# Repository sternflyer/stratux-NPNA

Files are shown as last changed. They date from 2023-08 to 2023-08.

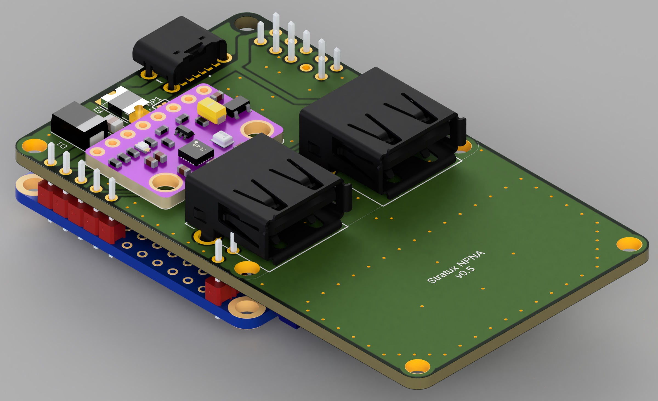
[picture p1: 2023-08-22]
PCB/PCB_BOTTOM_ISO.jpg

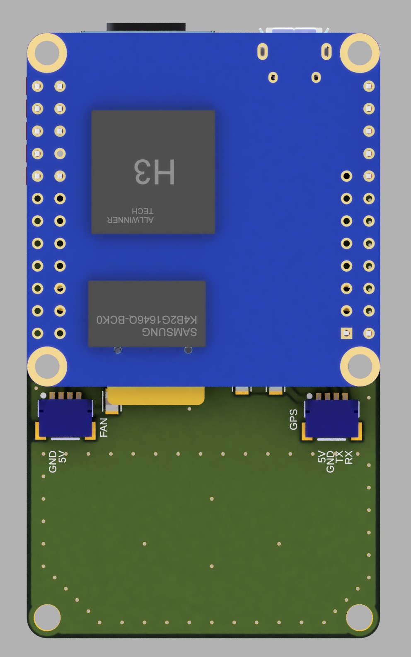
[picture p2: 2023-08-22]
PCB/PCB_TOP.jpg

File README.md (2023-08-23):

# stratux-NPNA
Stratux Europe running on a NanoPi Neo Air. Probably the smallest Stratux System possible. The case including fan and GPS ist juts 79x48x33mm in size.
Based on the wonderful work of https://github.com/b3nn0/stratux and https://github.com/VirusPilot/stratux-pi4.

```diff
-!!WARNING!!- This is work in progress. It might not work! It might fail after a while! DO NOT RELY ON IT DURING FLIGHT!!
```

# Installation
- Install a fresh version or Armbian Bullseye (I used 23.02.0 with 5.15.91 kernel) on your NanoPi Neo Air. Since there is no official Armbian support for the NanoPi Neo Air, you need to compile it yourself. For compatibility reason, you need to add ```BOOTFS_TYPE="fat"``` to the NanoPi Neo Air config file before compiling Armbian.
For best performance, install Armbian to the internal eMMC of the NanoPi Neo Air.
- Boot up Armbian Bullseye and connect to your WiFi. The initial Armbian setup script will guide you through that process.
- Download and run the Stratux NPNA setup script:
```
wget https://raw.githubusercontent.com/sternflyer/stratux-NPNA/main/stratux-NPNA-setup.sh
chmod +x stratux-NPNA-setup.sh
sudo ./stratux-NPNA-setup.sh
```

- Reboot when promted 

# Hardware
Description of the hardware used. You can find a shopping list at the end.

## NanoPi Neo Air
The NanoPi Neo Air is a very minimalistic SBC. Measuring only 40x40mm, it is probably one of the smallest SBC around. With no external connectors aside a mini USB port and a SD-Card slot. 
However, two USB-Ports, UART and I2C are available via pinheader. For detailed description see https://wiki.friendlyelec.com/wiki/index.php/NanoPi_NEO_Air.

## SDR
I'm using two Nooelec NESDR Nano 2 to receive ADS-B (1090 MHz) and OGN (868 MHz). Without plastic housing the SDRs fit under the custom PCB. The Fan provides proficient cooling. With a MCX to SMA adaptor you can remove the antennas for transport.

## GPS
I was having some difficulties to find a GPS that is working. The SDRs have quite some interference into the GPS frequency range and compromise reception. After many trial and error I found that the Beitian BE-252i module works best. It has a u-blox UBX-M10050 chip with a 25*25mm ceramic antenna.

## AHRS
I'm sing the popular GY-91 board with BMP280 and a MPU9250 accelerometer, gyroscope and compass. Due to EOL of MPU9250 cips, there are many boards with a MPU6050. The MPU6050 is the same as the MPU9250, but without a compass. Since compass is not used in Stratux, MPU6050 should work just as well (not tested).

## PCB
For connecting the peripherlas (two SDRs, a GPS, fan, and GY-91 AHRS board) I designed a PCB to connect to the pinheader. The smallest SMD components are 0805, still solderable by hand. Make sure to cut the pins of the USB-plugs as short as possible (after soldering) to prevent them from touching the NanoPi Air. Use the PCB spacers for correct distance between NanoPi Air and PCB.

## Case
The case can be 3D-printed. With the fan it provides sifficient cooling for the NanoPi Air and the SDRs. With the suction cup you can fix it to a window. Make sure to print it with white ABS oder PETG filament since it might get hot in direct sunlight. PLA will get soft if you leave it in the sun behind the window (aks me how i know...).

# Shopping list
These are the components you need: TBA
- NanoPi Neo Air (https://amzn.to/3KQvrtV)
- SDRs (https://amzn.to/3qOO4Ye)
- GPS Module (https://s.click.aliexpress.com/e/_Ddqhyxp)
- 30x30x7mm Fan (https://amzn.to/45lR8dI)
- GY-91 (https://amzn.to/3sjisum)
- PCB (need to get your own, GERBER files provided in [[PCB/](https://github.com/sternflyer/stratux-NPNA/PCB/stratux-NPNA-PCB_v05.zip))
- PCB components ([PCB/Partlist PCB.csv](https://github.com/sternflyer/stratux-NPNA/blob/main/PCB/Partlist%20PCB.csv))
- PETG or ABS for the case (https://amzn.to/3P5NSgH)
- Suction cup (https://amzn.to/3E7OOLq)

# NanoPi Neo Air vs. Raspberry Pi 3B+
Here is a small comparison of the NanoPi Neo Air and the Raspberry Pi 3B+ when running Stratux. Comparison was done with two Nooelec NESDR Nano 2, a GPS (USB BL1 GPS Module at rPi 3B+, Beitian BE-252i GPS on UART at NeoPi Nano Air) and a GY-91 Module as AHRS connected. TBA

| | raspberry Pi 3B+ | NanoPi Neo Air |
|-----|---|---|
Power Consumption | 1154 mA | 985 mA |
Avg. CPU load | 61 % | 64 % |
Avg. CPU Temp. | 42 °C | 45 °C |

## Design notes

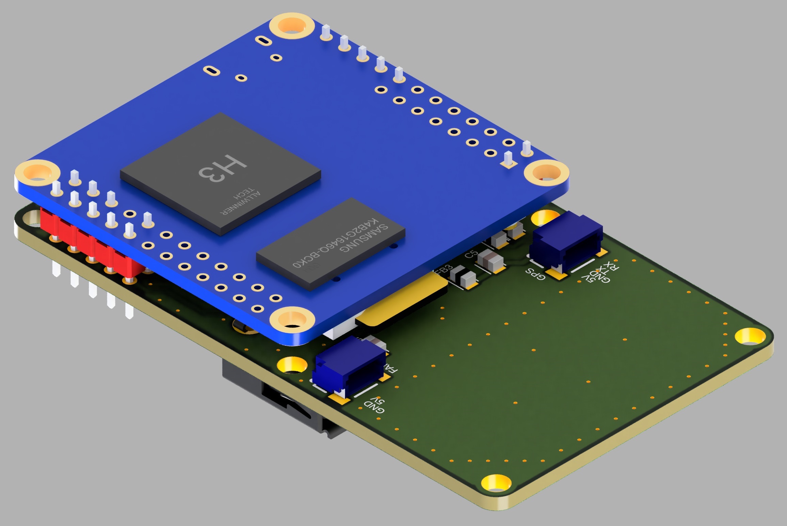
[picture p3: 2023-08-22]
PCB/PCB_TOP_ISO.jpg

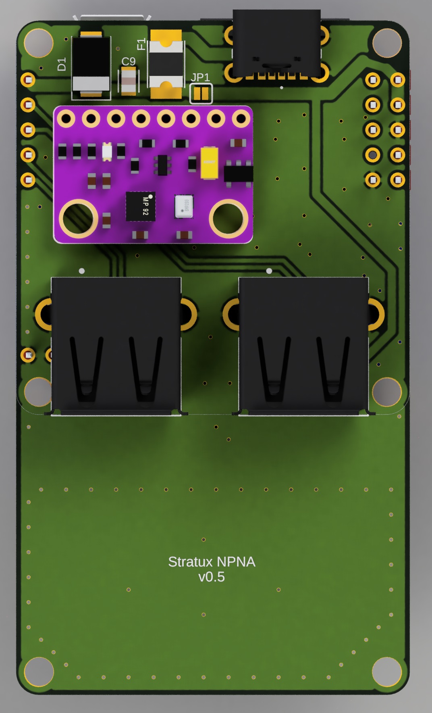
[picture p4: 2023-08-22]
PCB/PCB_BOTTOM.jpg

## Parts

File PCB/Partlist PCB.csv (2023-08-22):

Part | Value | Device | Package | Description | Source
C1 | 22uF | C_CHIP-0805 | 0805 | Capacitor | https://www.reichelt.de/smd-vielschicht-0805-22-f-x5r-10-6-3v-85-c-kem-x5r0805-22u-p207090.html
C2 | 100nF | C_CHIP-0805 | 0805 | Capacitor | https://www.reichelt.de/vielschicht-kerko-100nf-50v-125-c-kem-x7r0805-100n-p207073.html
C3 | 22uF | C_CHIP-0805 | 0805 | Capacitor | https://www.reichelt.de/smd-vielschicht-0805-22-f-x5r-10-6-3v-85-c-kem-x5r0805-22u-p207090.html
C4 | 100nF | C_CHIP-0805 | 0805 | Capacitor | https://www.reichelt.de/vielschicht-kerko-100nf-50v-125-c-kem-x7r0805-100n-p207073.html
C5 | 100nF | C_CHIP-0805 | 0805 | Capacitor | https://www.reichelt.de/vielschicht-kerko-100nf-50v-125-c-kem-x7r0805-100n-p207073.html
C6 | 100nF | C_CHIP-0805 | 0805 | Capacitor | https://www.reichelt.de/vielschicht-kerko-100nf-50v-125-c-kem-x7r0805-100n-p207073.html
C7 | 100nF | C_CHIP-0805 | 0805 | Capacitor | https://www.reichelt.de/vielschicht-kerko-100nf-50v-125-c-kem-x7r0805-100n-p207073.html
C8 | 22uF | C_CHIP-0805 | 0805 | Capacitor | https://www.reichelt.de/smd-vielschicht-0805-22-f-x5r-10-6-3v-85-c-kem-x5r0805-22u-p207090.html
C9 | 100nF | C_CHIP-0805 | 0805 | Capacitor | https://www.reichelt.de/vielschicht-kerko-100nf-50v-125-c-kem-x7r0805-100n-p207073.html
D1 | 1SMB5920B | SMBJ 5.0A-TR STM | DO-214AA/SMB | Zener Diode | https://www.reichelt.de/tvs-diode-unidirectional-5-v-600-w-do-214aa-smb-smbj-5-0a-tr-stm-p219609.html
F1 | 1812L010 | 1812L010 | FUSC4532X125 | Fuse | https://www.reichelt.de/smd-sicherung-smd-1206-traege-t-2a-belfuse-430020-p279446.html
FAN | Micro Sh 1.0 Jst 4 Pin | Micro Sh 1.0 Jst 4 Pin | 1X04_1MM_RA | Micro Sh 1.0 Jst 4 Pin | https://amzn.to/3sryfXW
FB1 | BLM21AG 331 | FB_BLM21AG102SN1D_0805(2012) | 0805 | Ferrite Bead | https://www.reichelt.de/ferrit-bead-smd-0805-blm21-330-ohm-blm21pg-331-p89688.html
FB2 | BLM21AG 331 | FB_BLM21AG102SN1D_0805(2012) | 0805 | Ferrite Bead | https://www.reichelt.de/ferrit-bead-smd-0805-blm21-330-ohm-blm21pg-331-p89688.html
FB3 | BLM21AG 331 | FB_BLM21AG102SN1D_0805(2012) | 0805 | Ferrite Bead | https://www.reichelt.de/ferrit-bead-smd-0805-blm21-330-ohm-blm21pg-331-p89688.html
FB5 | BLM21AG 601 | FB_BLM21AG102SN1D_0805(2012) | 0805 | Ferrite Bead | https://www.reichelt.de/emi-suppression-filter-smd0805-blm21-600-ohm-blm21ag-601-p89683.html
FB6 | BLM21AG 601 | FB_BLM21AG102SN1D_0805(2012) | 0805 | Ferrite Bead | https://www.reichelt.de/emi-suppression-filter-smd0805-blm21-600-ohm-blm21ag-601-p89683.html
GPS | Micro Sh 1.0 Jst 4 Pin | Micro Sh 1.0 Jst 4 Pin | 1X04_1MM_RA | Micro Sh 1.0 Jst 4 Pin | https://amzn.to/3sryfXW
GY-91 | GY-91 | GY-91 | GY-91 | GY-91 | https://amzn.to/3sjisum
USB-C | USB-C 6 Pin | USB-C 6 Pin | USB-C 6 Pin | USB-C Connector 6 Pin | https://amzn.to/3YMTQXd
USB1 | USB-A Plug | USB-A Plug | USB-A Plug | USB-A Connector | https://www.reichelt.de/usb-einbaubuchse-serie-a-gew-printmontage-usb-aw-p22184.html
USB2 | USB-A Plug | USB-A Plug | USB-A Plug | USB-A Connector | https://www.reichelt.de/usb-einbaubuchse-serie-a-gew-printmontage-usb-aw-p22184.html

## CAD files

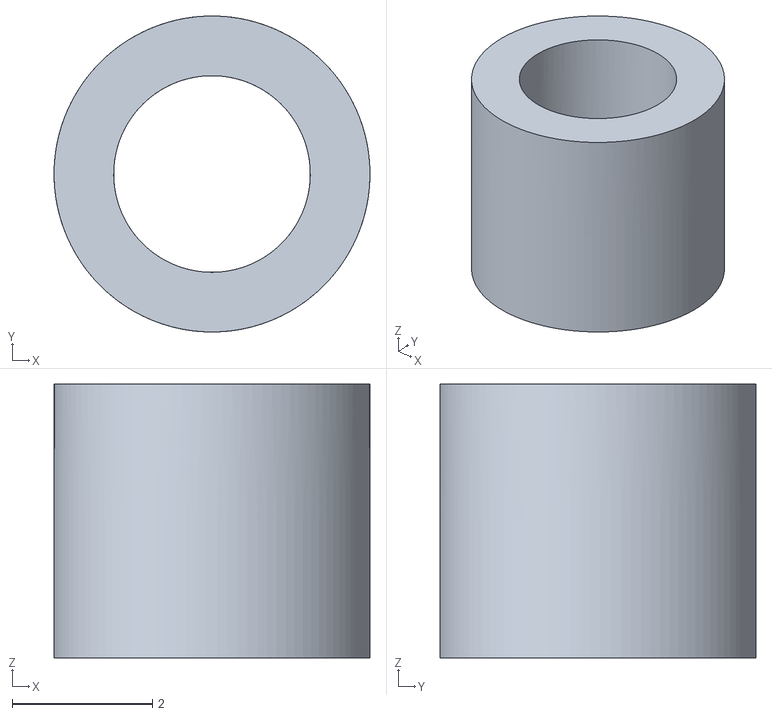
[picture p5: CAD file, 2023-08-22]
Case/stratux-NPNA PCB Spacer.stl
4.50 x 4.50 x 3.90

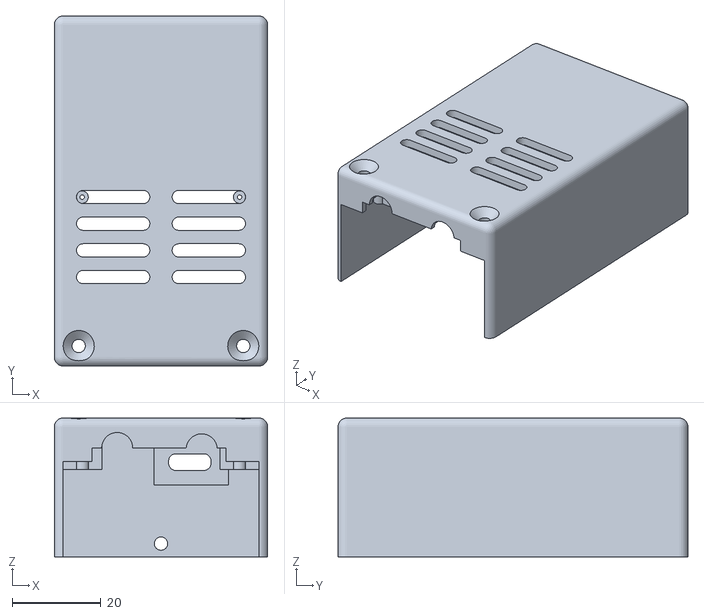
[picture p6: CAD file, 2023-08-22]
Case/stratux-NPNA Case Bottom.stl
48.0 x 78.7 x 31.2

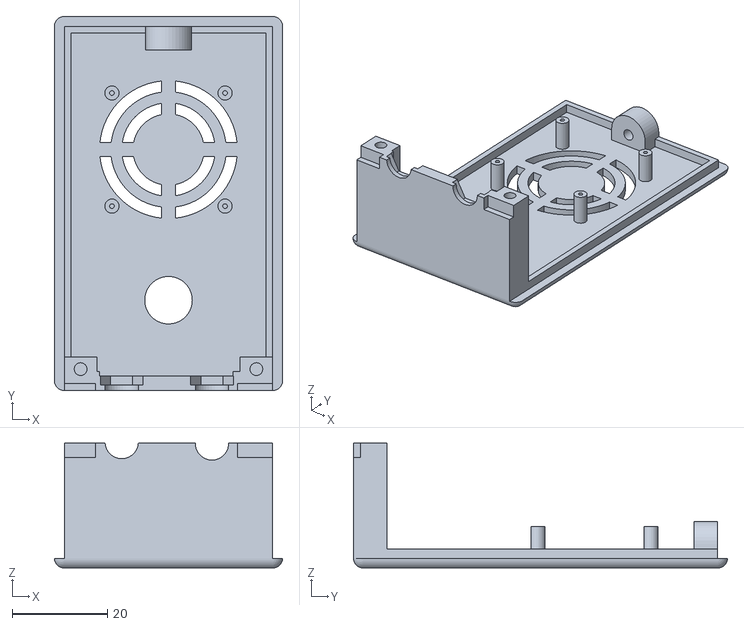
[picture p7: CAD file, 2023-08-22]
Case/stratux-NPNA Case Top.stl
48.0 x 78.7 x 26.3

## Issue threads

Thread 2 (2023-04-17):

PCB for NPNA Board connections

D4veBowm4n, 2023-04-17:
This is a really interesting port of the stratux project - I'd like to build one since my RPi went kaput. Would you be willing to share the PCB layout you designed? Or at least the schematic for connecting the SDRs + GPS + AHRS board?

sternflyer, 2023-04-19:
Added the PCB files and a partlist for the components.
However, this is still work in progress.
I'm currently seeing issues with the GPS-signal dropping when enabling the SDRs. Hence the ferrite beads on the PCB. It helps a bit, but signal still drops significantly.

D4veBowm4n, 2023-05-02:
Ok, thank you - I'll check it out!

Closed 2023-05-02.

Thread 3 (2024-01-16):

Fan header

Dolqus, 2024-01-16:
Hi, I really like your project and when I have time, I will order and try it out.
I noticed that the fan on amazon you linked has the standard 2 pin connector while the PCB fan header is the Micro Sh 1.0 Jst 4 Pin socket.
Wouldn't it be better to just put a standard 90° 2 pin fan header at that position instead?

sternflyer, 2024-01-16:
Thank you for your comment.
Space is at premium and the standard 90° 2-Pin header are quite large, specially in height.
Since a Micro JST header is needed for GPS anyhow, I used it for the fan header as well. I bought a kit from Amazon (https://amzn.to/3vJzTG0) that included wires with plugs. I just soldered the plug to the fan.

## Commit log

2023-02-14 Device Name matched for rPi
2023-02-16 Adjusted fan Pin to GPIO.7 / H3 Pin 203
2023-02-20 GPS UART Bug fixed
    Correct configuration sent to u-blox when connecting via UART
2023-02-20 use i2c-0 for pin compatibility on NanoPi Neo Air
2023-04-19 Create Partlist PCB
2023-04-19 Rename Partlist PCB to Partlist PCB.csv
    [Partlist PCB.csv]
2023-08-22 Update Partlist PCB.csv
    [Partlist PCB.csv]
